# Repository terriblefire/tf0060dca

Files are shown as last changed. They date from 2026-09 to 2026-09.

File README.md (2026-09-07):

# TF0060DCA








Drop-in replacement for the Taito TC0060DCA custom dual digitally-controlled
attenuator (as used on the Operation Wolf sound board, Taito schematic
W5100215A). Two LM1972 digital attenuators driven from the original 8-bit
parallel volume bus by a CH32V203C8T6 RISC-V MCU, with a measured calibration
mapping.

The primary aim of this project was to give me repro modules for my Operation 
Wolf machine but I also passed the measured curves on to MAME where they have 
been integrated. 

## Community

Questions, build reports and general chat: [join the Discord](https://discord.gg/awMzHfB86T).

## The repro matches the original

The key result of this project: measured on the [test fixture](testfixture/),
the TF0060DCA repro reproduces the original TC0060DCA's volume response to
within about 2% across the working range. Both sweeps below were taken at the
same drive level and are referenced to their full-volume (SD 255) output; the
x-axis is the machine's SD bus convention (0 = silence, 255 = full volume).
Where the curves part company at the bottom is just the two measurement runs'
differing noise floors.

Original vs repro measured response

Source data: [raw_curve_second_measure.csv](measured/raw_curve_second_measure.csv)
(original), [ch32_measured.csv](measured/ch32_measured.csv) (repro).

**Firmware response.** The repro's curve is fully explained by its firmware:
the computed line is derived from the `lm1972_mapping` table in
[main.c](firmware/CH32V203C8T6/User/main.c) and the LM1972 datasheet
attenuation values (SNAS094D Table 1): SD codes 0-86 map to LM1972 mute
(codes >= 0x7F = 100 dB), SD 87 gives -74.5 dB, SD 88 -44.5 dB, rising to
-4.5 dB at SD 255. The measured CH32 sweep matches it within about 2%
everywhere above the rig's ~ -23 dB noise floor, which hides the mute region.

CH32 firmware response, computed vs measured

## Test fixture

The fixture that produced the measurements: a Raspberry Pi Zero drives the SD
volume bus and clocks while the DUT's audio output is measured. It carries two
20-pin SIP sockets so an original TC0060DCA and the TF0060DCA replacement can
be exercised side by side.

| | |
|---|---|
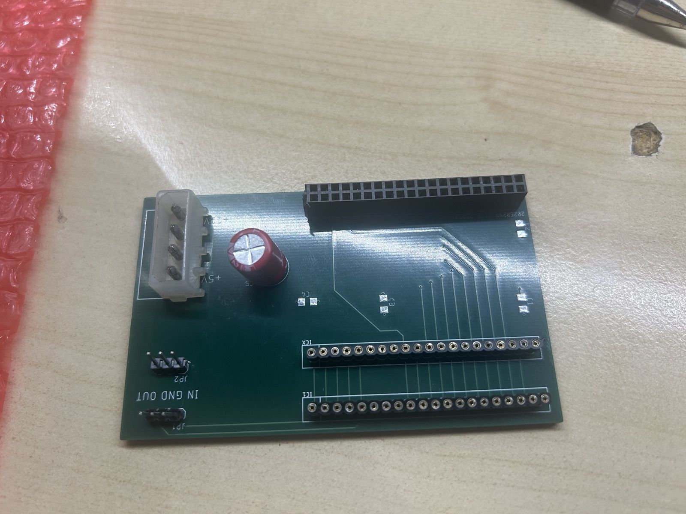
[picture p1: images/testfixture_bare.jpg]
Bare test fixture PCB
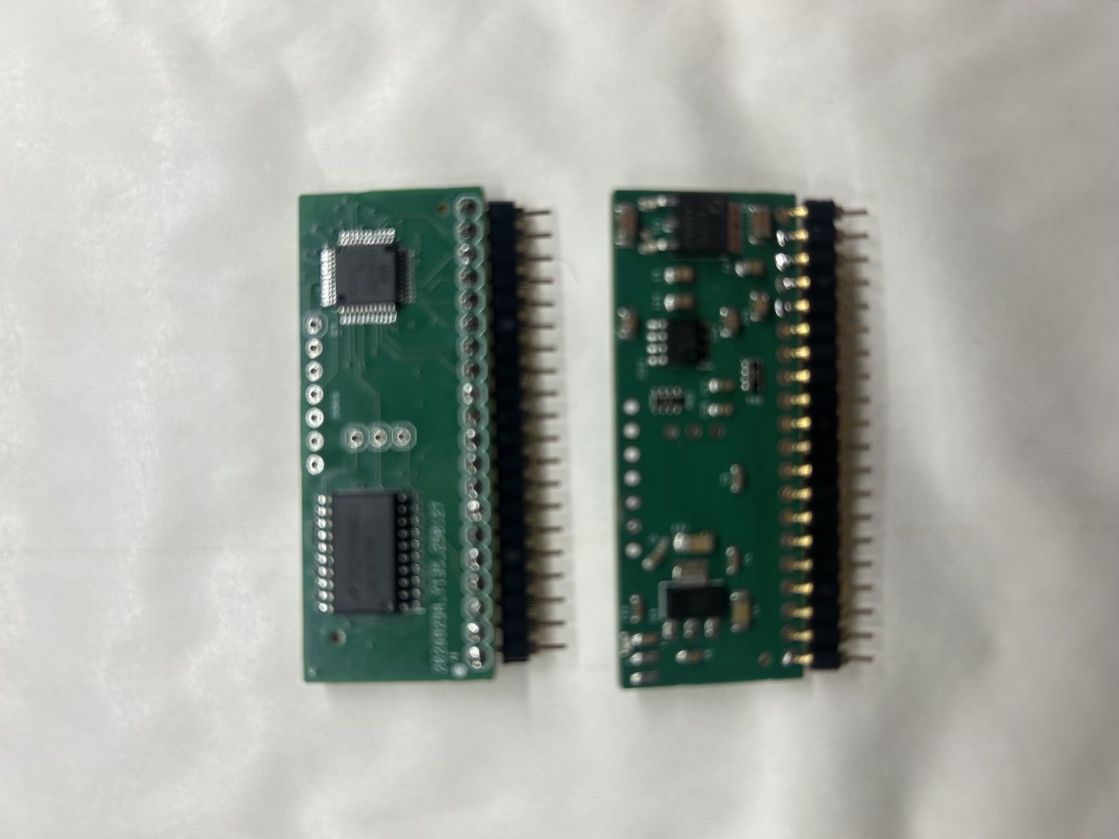
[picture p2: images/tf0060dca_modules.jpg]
Replacement modules, front and back
|  |  |
| *Bare fixture: Molex power in, Pi Zero header, two SIP-20 sockets* | *TF0060DCA replacement modules* |
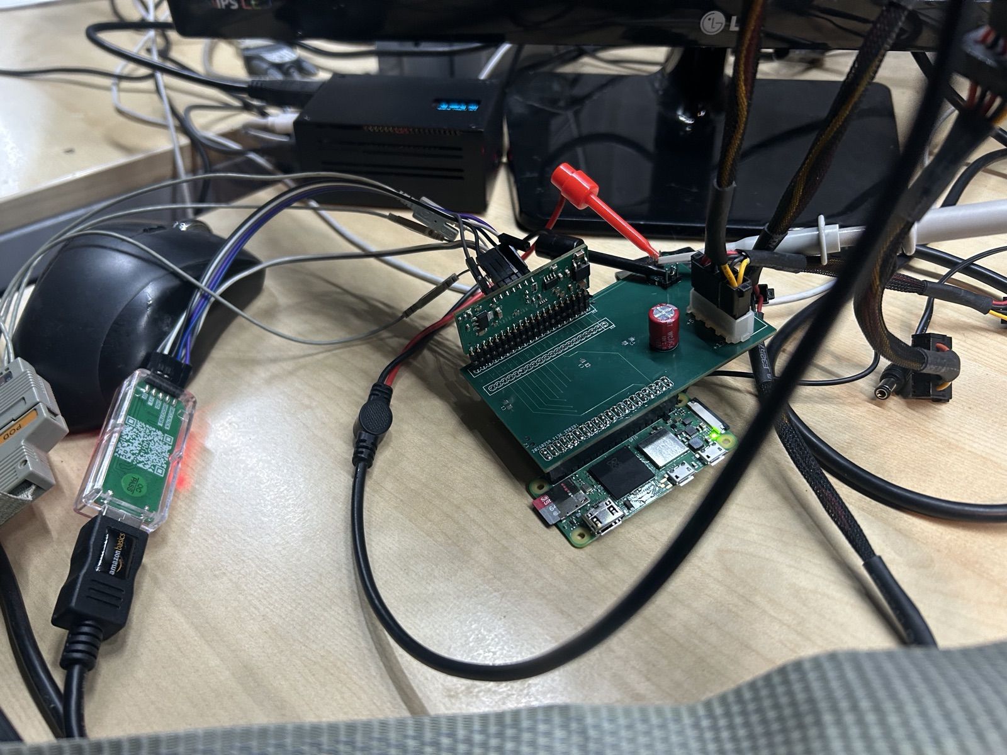
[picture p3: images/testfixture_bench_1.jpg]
Fixture on the bench
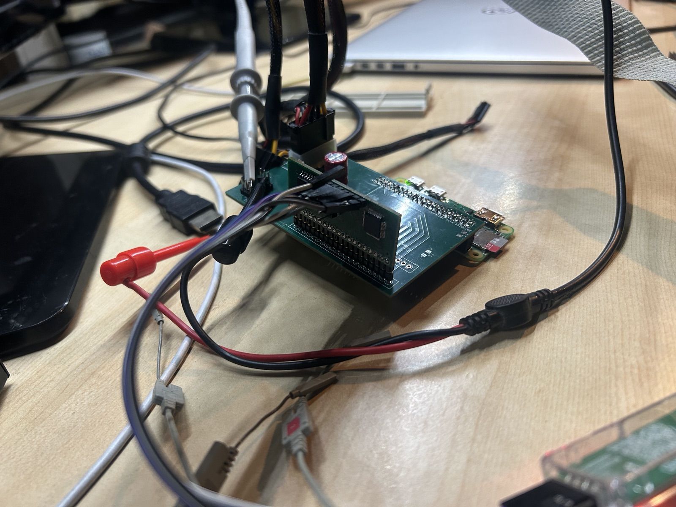
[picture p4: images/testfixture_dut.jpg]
Fixture with DUT fitted
|  |  |
| *On the bench, mounted on a Pi Zero* | *With a device under test fitted* |
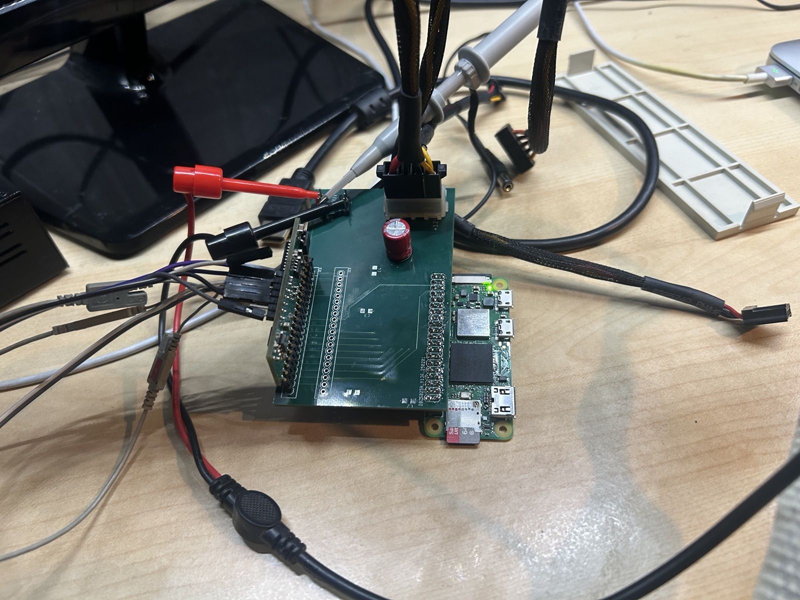
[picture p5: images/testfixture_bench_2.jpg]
Bench, second angle
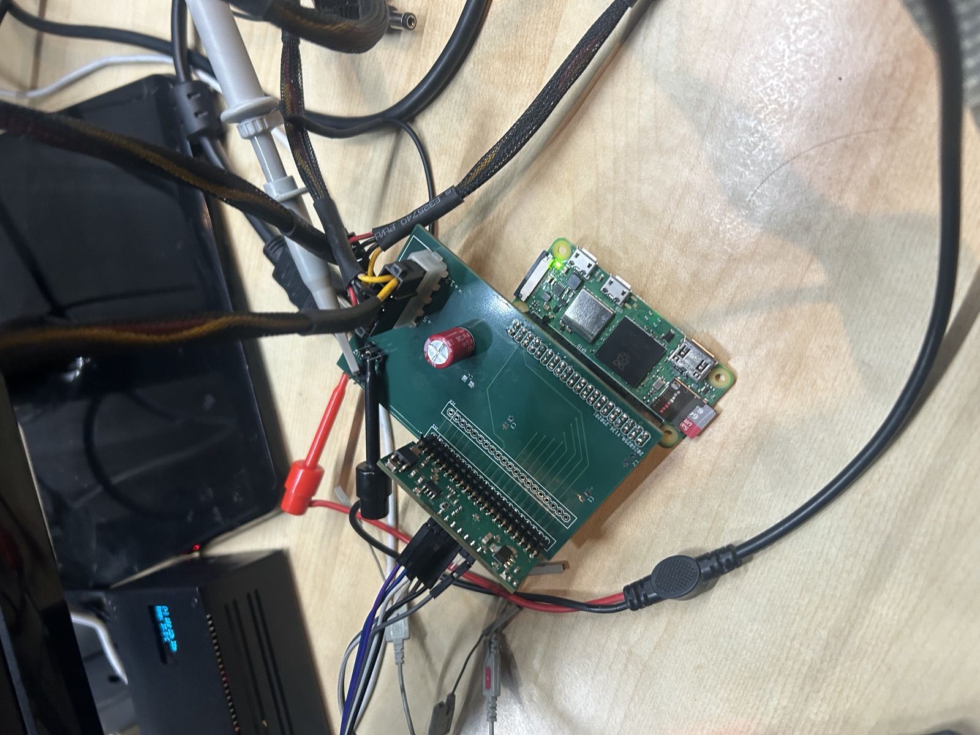
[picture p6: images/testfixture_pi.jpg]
Overhead view on the Pi Zero
|  |  |
| *Probing during a measurement run* | *Overhead: Pi Zero and fixture* |

## TC0060DCA pin 7 (V_B)

Pin 7 of the original TC0060DCA has been asked about; the evidence from the
original hardware and this project:

- **Original Taito schematic** (W5100215A, sheet 4-2, IC49): pin 7 is strapped
  directly to the same ground rail as pins 6, 10 and 20. There is no external
  bias network (no capacitor or divider). Pin 8 is drawn as an unconnected
  stub (N.C.).
- **Test fixture**: a real TC0060DCA runs correctly with pin 7 tied to GND —
  the measured response above was captured that way.
- **This replacement** leaves pin 7 unconnected (net `V_B`) and pin 8 N.C.,
  and functions in the host board.

So pin 7 is a ground-referenced bias/substrate connection ("V_B"), tied to 0 V
in the machine and carrying no signal; a replacement can safely leave it
unconnected. It is not a volume or audio pin.

## Design notes (FAQ)

**Are C8-C11, C14 and C15 polarized?** No. They are drawn with Eagle's `C-US`
device, whose American-style symbol has one straight and one curved plate for
*any* capacitor - a polarized cap in Eagle carries an explicit "+" mark, which
these don't have. Physically they are 0805 ceramic (MLCC) parts, inherently
non-polar, used as AC coupling in the audio path.

**Volume conventions.** The machine's SD bus counts up (0 = silence, 255 =
full volume). The LM1972 register counts the other way (datasheet SNAS094D
Table 1: code 0x00 = 0.0 dB, 0.5 dB/step to 47.5 dB at code 95, 1.0 dB/step
to 78 dB at code 126, codes 0x7F-0xFF = 100 dB mute). The firmware's
`lm1972_mapping` table translates between the two. The legacy
[measured/measured.csv](measured/measured.csv) is indexed by attenuation
step (0 = full volume), not by SD code.

**What value are the coupling caps?** These are AC couplers, so the exact
value is not critical - it only sets the high-pass corner, which sits far
below audio for anything in this region. The design value was a nominal 6 uF;
on the JLCPCB production run the part matcher resolved this to a 10 uF X5R
(Samsung CL21A106KOQNNNE, LCSC C1713), which is what is fitted on assembled
boards and what the schematic now records. If hand-building, 4.7 uF, 6.8 uF
or 10 uF are all fine.

- `eagle/` - EAGLE schematic/board plus CAM, BOM/CPL and check tooling
  (`make help` for targets; gerbers and PDF build via the terriblefire78
  Docker images)
- `firmware/` - CH32V203 firmware (builds in `terriblefire78/mrs:latest`,
  or `make firmware` from the repo root)
- `testfixture/` - EAGLE test fixture board
- `measured/` - measured attenuation data and calibration table generator
- `gerbers/` - manufactured revisions (JLCPCB)

## License

Copyright (c) 2026 Stephen Leary (TerribleFire).

This design and its firmware are licensed under
[Creative Commons Attribution 4.0 International](LICENSE) (CC BY 4.0): you may
use, modify, manufacture and sell derivatives for any purpose, provided you
credit the original design and work.

WCH vendor sources under `firmware/` (Nanjing Qinheng Microelectronics) retain
their own copyright notices.

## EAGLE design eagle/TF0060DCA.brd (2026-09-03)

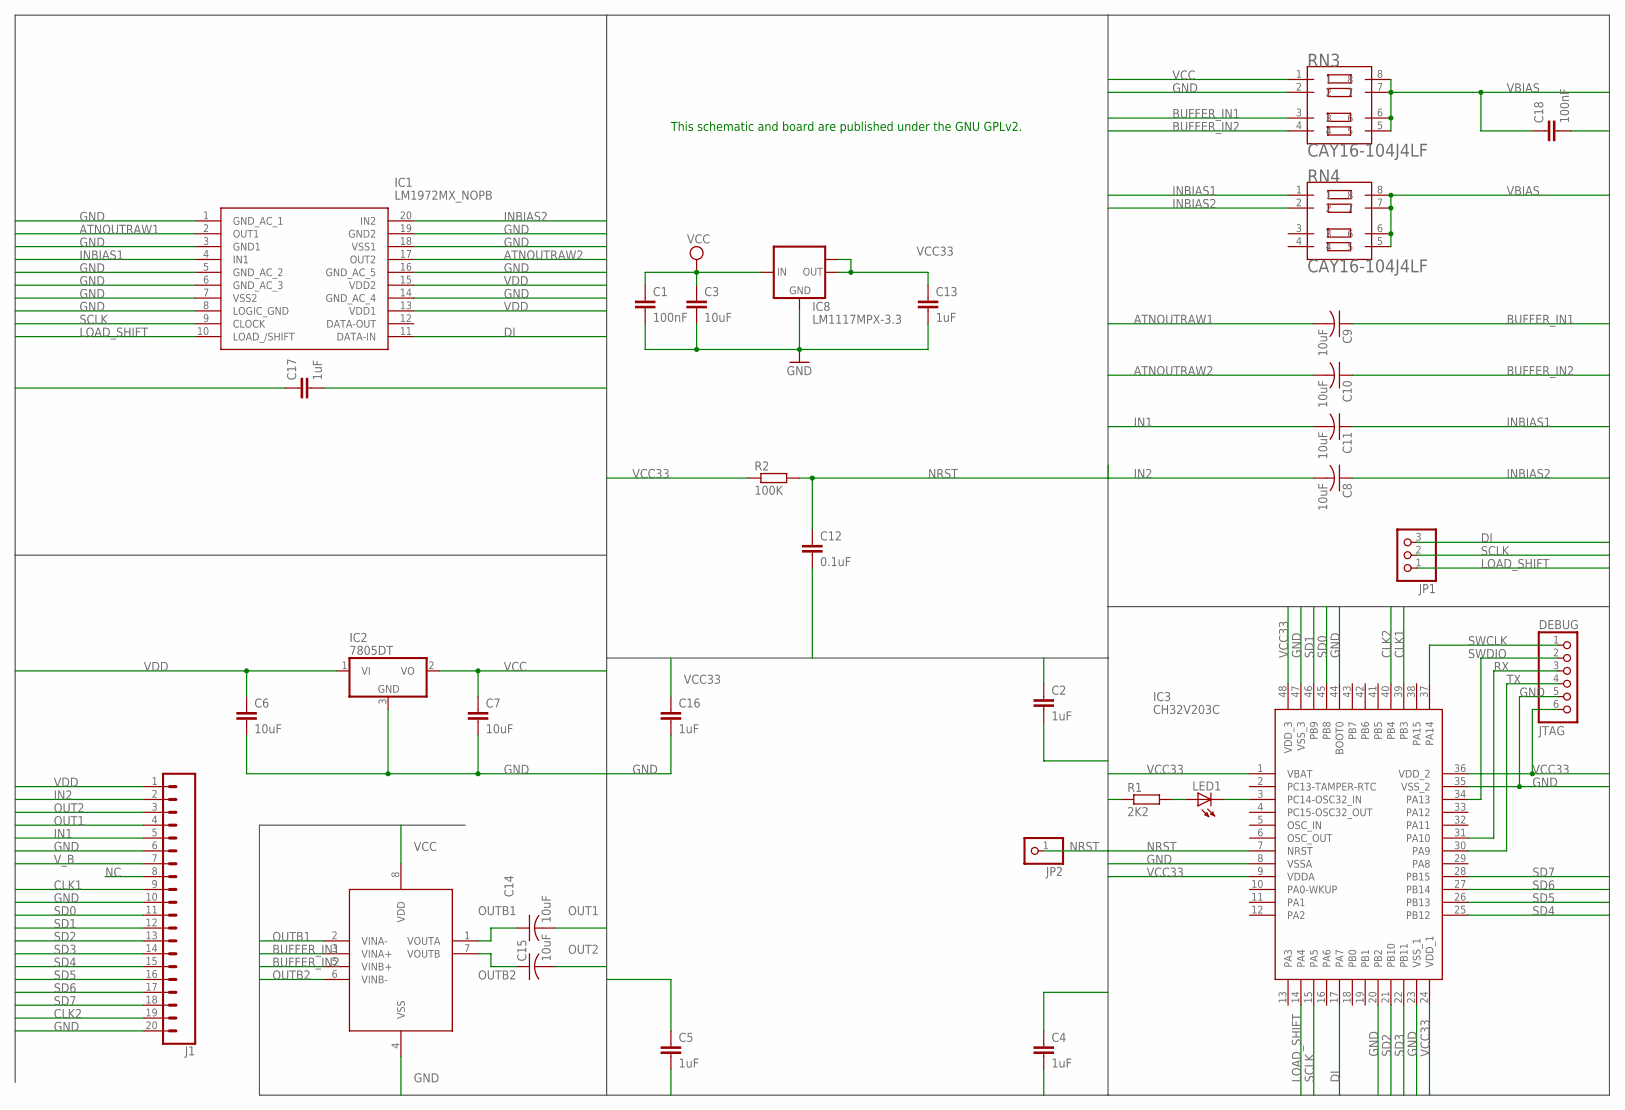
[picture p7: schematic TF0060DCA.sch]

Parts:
C1: 100nF; C1206
C2, C4, C5, C16, C17: 1uF; C0603
C3: 10uF; C0603
C6, C7: 10uF; C1206
C8, C9, C10, C11, C14, C15: 10uF; C0805
C12: 0.1uF; C0603
C13: 1uF; C1206
C18: 100nF; C0603
DEBUG: JTAG; 1X06_ROUND
IC1: LM1972MX_NOPB; SOIC127P1030X265-20N
IC2: 7805DT; TO252
IC3: CH32V203C; QFP50P900X900X160-48N
IC8: LM1117MPX-3.3; SOT223
IC12: MCP6002T-I_SN; SOIC127P600X175-8N
J1: CONN_20; 1X20
JP1: PINHD-1X3; 1X03
JP2: PINHD-1X1; 1X01
LED1: LEDCHIPLED_0603; CHIPLED_0603
R1: 2K2; R0603
R2: 100K; R0603
RN3, RN4: CAY16-104J4LF; RESCAXE80P320X160-8N

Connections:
ATNOUTRAW1: C9.2, IC1.2 (OUT1)
ATNOUTRAW2: C10.2, IC1.17 (OUT2)
BUFFER_IN1: C9.1, IC12.3 (VINA+), RN3.3
BUFFER_IN2: C10.1, IC12.5 (VINB+), RN3.4
CLK1: IC3.39 (PB3), J1.9
CLK2: IC3.40 (PB4), J1.19
DI: IC1.11 (DATA-IN), IC3.17 (PA7), JP1.3
GND: C1.2, C2.2, C3.2, C4.2, C5.2, C6.2, C7.2, C12.2, C13.2, C16.2, C17.2, C18.2, DEBUG.5, IC1.1 (GND_AC_1), IC1.3 (GND1), IC1.5 (GND_AC_2), IC1.6 (GND_AC_3), IC1.7 (VSS2), IC1.8 (LOGIC_GND), IC1.14 (GND_AC_4), IC1.16 (GND_AC_5), IC1.18 (VSS1), IC1.19 (GND2), IC2.3 (GND), IC3.8 (VSSA), IC3.20 (PB2), IC3.23 (VSS_1), IC3.35 (VSS_2), IC3.44 (BOOT0), IC3.47 (VSS_3), IC8.1 (GND), IC12.4 (VSS), J1.6, J1.10, J1.20, RN3.2
IN1: C11.2, J1.5
IN2: C8.2, J1.2
INBIAS1: C11.1, IC1.4 (IN1), RN4.1
INBIAS2: C8.1, IC1.20 (IN2), RN4.2
LOAD_SHIFT: IC1.10 (LOAD_/SHIFT), IC3.14 (PA4), JP1.1
unnamed: IC3.3 (PC14-OSC32_IN), LED1.C
unnamed: LED1.A, R1.2
NC: J1.8
NRST: C12.1, IC3.7 (NRST), JP2.1, R2.2
OUT1: C14.2, J1.4
OUT2: C15.2, J1.3
OUTB1: C14.1, IC12.1 (VOUTA), IC12.2 (VINA-)
OUTB2: C15.1, IC12.6 (VINB-), IC12.7 (VOUTB)
RX: DEBUG.3, IC3.31 (PA10)
SCLK: IC1.9 (CLOCK), IC3.15 (PA5), JP1.2
SD0: IC3.45 (PB8), J1.11
SD1: IC3.46 (PB9), J1.12
SD2: IC3.21 (PB10), J1.13
SD3: IC3.22 (PB11), J1.14
SD4: IC3.25 (PB12), J1.15
SD5: IC3.26 (PB13), J1.16
SD6: IC3.27 (PB14), J1.17
SD7: IC3.28 (PB15), J1.18
SWCLK: DEBUG.1, IC3.37 (PA14)
SWDIO: DEBUG.2, IC3.34 (PA13)
TX: DEBUG.4, IC3.30 (PA9)
VBIAS: C18.1, RN3.5, RN3.6, RN3.7, RN3.8, RN4.5, RN4.6, RN4.7, RN4.8
VCC: C1.1, C3.1, C7.1, C17.1, IC2.2 (VO), IC8.3 (IN), IC12.8 (VDD), RN3.1
VCC33: C2.1, C4.1, C5.1, C13.1, C16.1, DEBUG.6, IC3.1 (VBAT), IC3.9 (VDDA), IC3.24 (VDD_1), IC3.36 (VDD_2), IC3.48 (VDD_3), IC8.2 (OUT), IC8.TAB (OUT1), R1.1, R2.1
VDD: C6.1, IC1.13 (VDD1), IC1.15 (VDD2), IC2.1 (VI), J1.1
V_B: J1.7

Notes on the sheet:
This schematic and board are published under the GNU GPLv2.

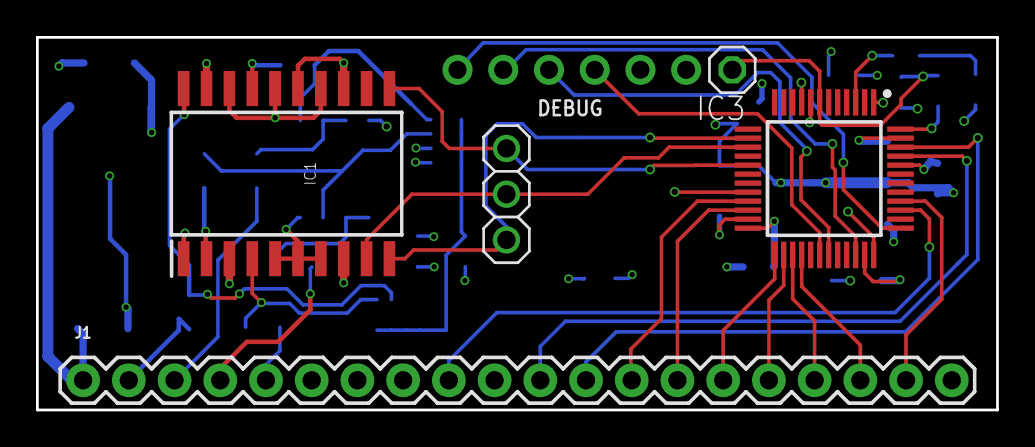
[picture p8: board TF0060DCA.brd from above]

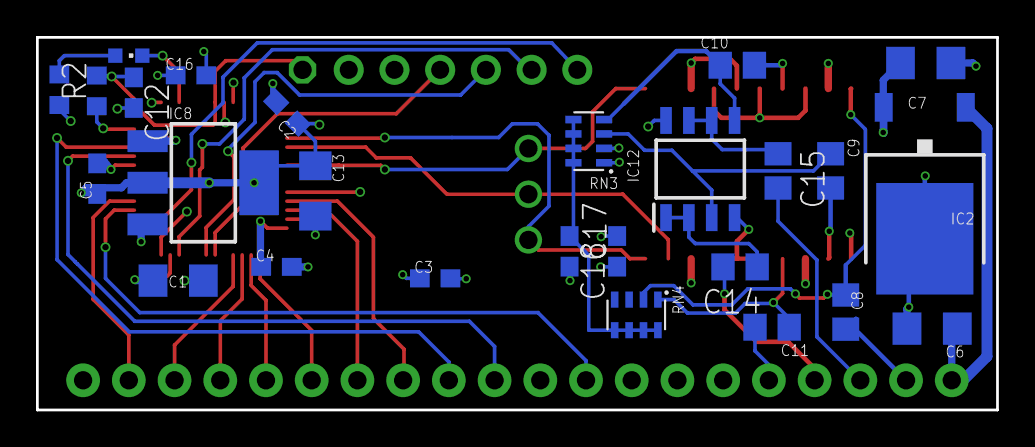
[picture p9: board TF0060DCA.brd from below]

Board: 4 copper layers, 53.3 x 20.7 mm, 32 parts (26 on the bottom side), 37 nets.

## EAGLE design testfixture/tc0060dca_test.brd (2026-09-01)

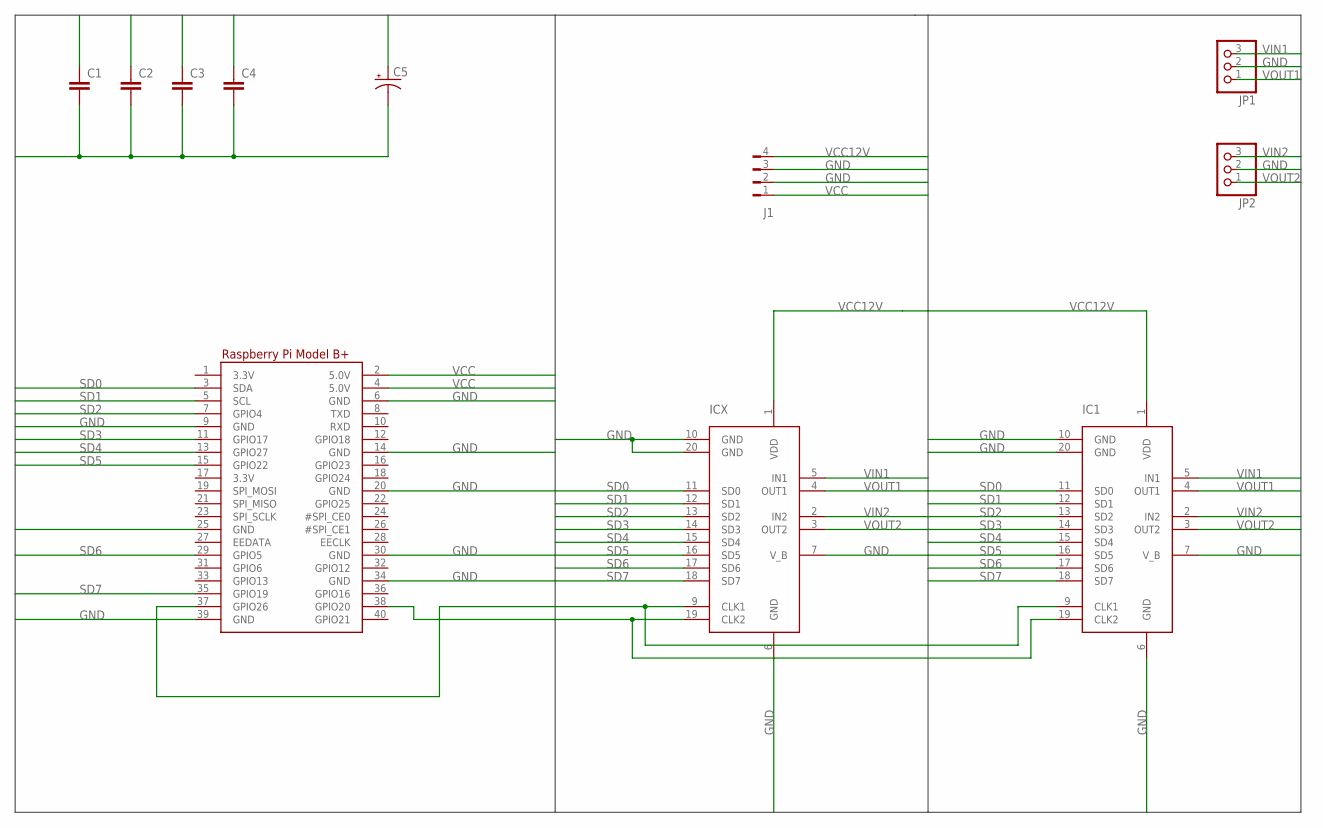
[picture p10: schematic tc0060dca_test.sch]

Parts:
C1, C2, C3, C4: CC1206; C1206
C5: CPOL-USTT5D9; TT5D9
IC1: TC0060DCA; 1X20
ICX: TC0060DCA; 1X20
J1: FLOP-4W; FLOP-4V
JP1, JP2: PINHD-1X3; 1X03
RPI1: RASPBERRYPI_BPLUS_IDC; 2X20

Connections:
GND: C1.2, C2.2, C3.2, C4.2, C5.-, IC1.6 (GND), IC1.7 (V_B), IC1.10 (GND), IC1.20 (GND), ICX.6 (GND), ICX.7 (V_B), ICX.10 (GND), ICX.20 (GND), J1.2, J1.3, JP1.2, JP2.2, RPI1.6 (GND), RPI1.9 (GND), RPI1.14 (GND), RPI1.20 (GND), RPI1.25 (GND), RPI1.30 (GND), RPI1.34 (GND), RPI1.39 (GND)
unnamed: IC1.9 (CLK1), ICX.9 (CLK1), RPI1.37 (GPIO26)
unnamed: IC1.19 (CLK2), ICX.19 (CLK2), RPI1.38 (GPIO20)
SD0: IC1.11 (SD0), ICX.11 (SD0), RPI1.3 (SDA)
SD1: IC1.12 (SD1), ICX.12 (SD1), RPI1.5 (SCL)
SD2: IC1.13 (SD2), ICX.13 (SD2), RPI1.7 (GPIO4)
SD3: IC1.14 (SD3), ICX.14 (SD3), RPI1.11 (GPIO17)
SD4: IC1.15 (SD4), ICX.15 (SD4), RPI1.13 (GPIO27)
SD5: IC1.16 (SD5), ICX.16 (SD5), RPI1.15 (GPIO22)
SD6: IC1.17 (SD6), ICX.17 (SD6), RPI1.29 (GPIO5)
SD7: IC1.18 (SD7), ICX.18 (SD7), RPI1.35 (GPIO19)
VCC: C1.1, C2.1, C3.1, J1.1, RPI1.2 (5.0V), RPI1.4 (5.0V)
VCC12V: C4.1, C5.+, IC1.1 (VDD), ICX.1 (VDD), J1.4
VIN1: IC1.5 (IN1), ICX.5 (IN1), JP1.3
VIN2: IC1.2 (IN2), ICX.2 (IN2), JP2.3
VOUT1: IC1.4 (OUT1), ICX.4 (OUT1), JP1.1
VOUT2: IC1.3 (OUT2), ICX.3 (OUT2), JP2.1

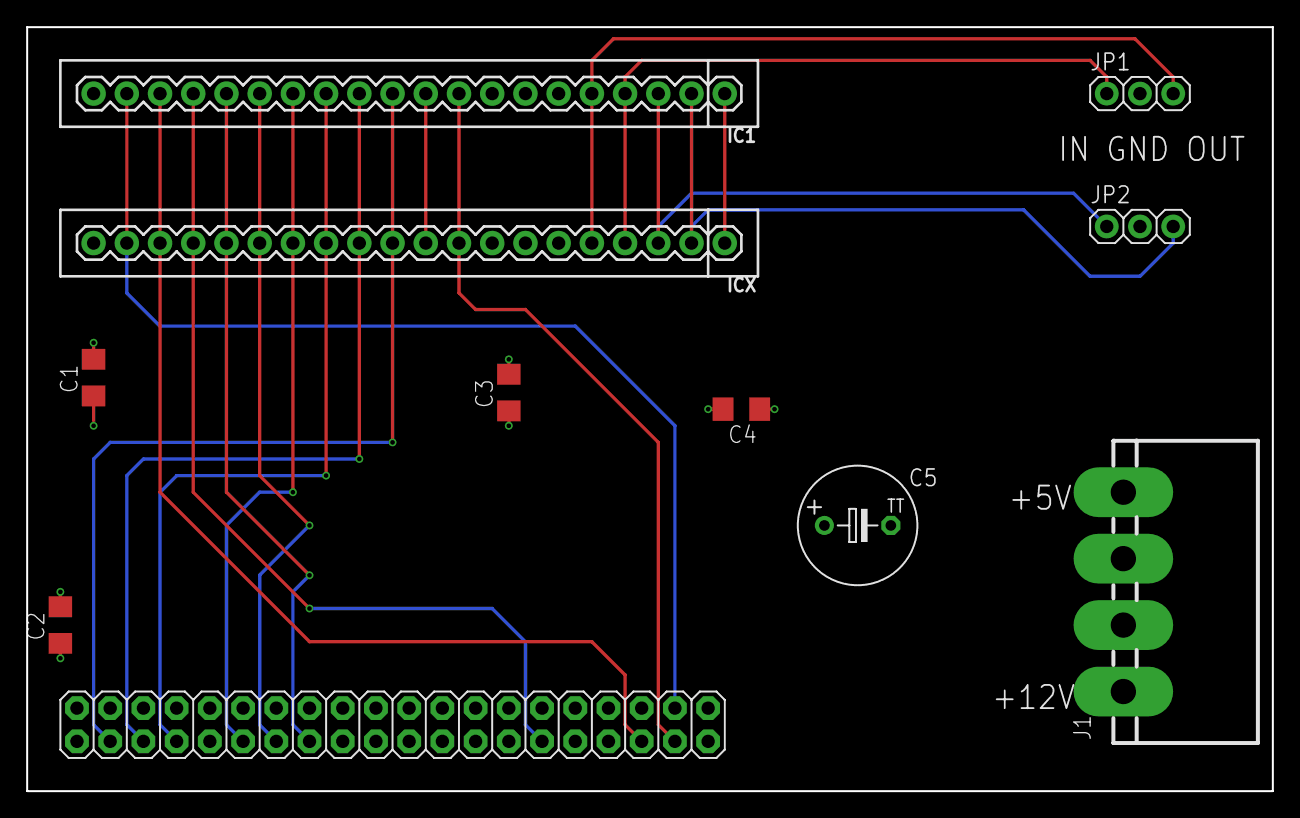
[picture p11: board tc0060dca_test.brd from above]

Board: 4 copper layers, 95.2 x 58.4 mm, 11 parts (0 on the bottom side), 17 nets.

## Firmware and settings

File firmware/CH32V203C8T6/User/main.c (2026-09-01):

/********************************** (C) COPYRIGHT *******************************
 * File Name          : main.c
 * Author             : WCH
 * Version            : V1.0.0
 * Date               : 2021/06/06
 * Description        : Main program body.
 *********************************************************************************
 * Copyright (c) 2021 Nanjing Qinheng Microelectronics Co., Ltd.
 * Attention: This software (modified or not) and binary are used for 
 * microcontroller manufactured by Nanjing Qinheng Microelectronics.
 *******************************************************************************/

/*
 *@Note
 *USART Print debugging routine:
 *USART1_Tx(PA9).
 *This example demonstrates using USART1(PA9) as a print debug port output.
 *
 */

#include "debug.h"

#define LM1972_CH1_ADDRESS 0 
#define LM1972_CH2_ADDRESS 1

#define LM1972_VOL_MAX     0
#define LM1972_VOL_MUTE    128

static u_int8_t lm1972_mapping[] = {0x80,0x7F,0x7F,0x7F,0x7F,0x7F,0x7F,0x7F,0x7F,0x7F,0x7F,0x7F,0x7F,0x7F,0x7F,0x7F,
                                    0x7F,0x7F,0x7F,0x7F,0x7F,0x7F,0x7F,0x7F,0x7F,0x7F,0x7F,0x7F,0x7F,0x7F,0x7F,0x7F,
                                    0x7F,0x7F,0x7F,0x7F,0x7F,0x7F,0x7F,0x7F,0x7F,0x7F,0x7F,0x7F,0x7F,0x7F,0x7F,0x7F,
                                    0x7F,0x7F,0x7F,0x7F,0x7F,0x7F,0x7F,0x7F,0x7F,0x7F,0x7F,0x7F,0x7F,0x7F,0x7F,0x7F,
                                    0x7F,0x7F,0x7F,0x7F,0x7F,0x7F,0x7F,0x7F,0x7F,0x7F,0x7F,0x7F,0x7F,0x7F,0x7F,0x7F,
                                    0x7F,0x7F,0x7F,0x7F,0x7F,0x7F,0x7F,0x7A,0x59,0x50,0x48,0x43,0x41,0x3E,0x3C,0x3A,
                                    0x39,0x37,0x36,0x35,0x34,0x33,0x32,0x31,0x30,0x2F,0x2E,0x2D,0x2C,0x2B,0x2B,0x2A,
                                    0x29,0x28,0x28,0x27,0x26,0x26,0x25,0x24,0x24,0x23,0x23,0x22,0x22,0x21,0x21,0x20,
                                    0x20,0x1F,0x1F,0x1E,0x1E,0x1D,0x1D,0x1C,0x1C,0x1B,0x1B,0x1A,0x1A,0x19,0x19,0x18,
                                    0x18,0x17,0x17,0x17,0x16,0x16,0x16,0x15,0x15,0x14,0x14,0x14,0x14,0x13,0x13,0x13,
                                    0x12,0x12,0x12,0x12,0x11,0x11,0x11,0x11,0x10,0x10,0x10,0x10,0x10,0x0F,0x0F,0x0F,
                                    0x0F,0x0E,0x0E,0x0E,0x0E,0x0E,0x0E,0x0D,0x0D,0x0D,0x0D,0x0D,0x0D,0x0C,0x0C,0x0C,
                                    0x0C,0x0C,0x0C,0x0C,0x0B,0x0B,0x0B,0x0B,0x0B,0x0B,0x0B,0x0B,0x0B,0x0B,0x0A,0x0A,
                                    0x0A,0x0A,0x0A,0x0A,0x0A,0x0A,0x0A,0x0A,0x0A,0x0A,0x0A,0x0A,0x0A,0x0A,0x09,0x09,
                                    0x09,0x09,0x09,0x09,0x09,0x09,0x09,0x09,0x09,0x09,0x09,0x09,0x09,0x09,0x09,0x09,
                                    0x09,0x09,0x09,0x09,0x09,0x09,0x09,0x09,0x09,0x09,0x09,0x09,0x09,0x09,0x09,0x09};

static uint16_t ch1_volume_data = 255;
static uint16_t ch1_volume_last = 0;

static uint16_t ch2_volume_data = 255;
static uint16_t ch2_volume_last = 0;

void CLK1_IRQ (void) __attribute__ ((interrupt ("WCH-Interrupt-fast")));  // Line 3
void CLK2_IRQ (void) __attribute__ ((interrupt ("WCH-Interrupt-fast")));  // Line 4

void CLK1_IRQ (void) {
    EXTI->INTFR = EXTI_Line3;
    ch1_volume_data = (uint16_t)GPIOB->INDR >> 8;
    return;
}

void CLK2_IRQ (void) {
    EXTI->INTFR = EXTI_Line4;
    ch2_volume_data = (uint16_t)GPIOB->INDR >> 8;
    return;
}


/*********************************************************************
 * @fn      SPI1_ReadWriteByte
 *
 * @brief   SPI1 read or write one byte.
 *
 * @param   TxData - write one byte data.
 *
 * @return  Read one byte data.
 */
void SPI1_WriteByte(u8 TxData)
{
    u8 i = 0;
    while(SPI_I2S_GetFlagStatus(SPI1, SPI_I2S_FLAG_TXE) == RESET);
    SPI_I2S_SendData(SPI1, TxData);
    i = 0;
}

void SPI1_WriteChannel(u8 chan, u8 val)
{
    GPIO_WriteBit (GPIOA, GPIO_Pin_4, Bit_RESET); 
    SPI1_WriteByte(chan);
    SPI1_WriteByte(lm1972_mapping[val]);
    //SPI1_WriteByte(val);
    Delay_Us (10);
    GPIO_WriteBit (GPIOA, GPIO_Pin_4, Bit_SET); 
}


/*********************************************************************
 * @fn      SPI_1Lines_HalfDuplex_Init
 *
 * @brief   Configuring the SPI for half-duplex communication.
 *
 * @return  none
 */
void SPI_1Lines_HalfDuplex_Init(void)
{
    printf("Entering SPI_1Lines_HalfDuplex_Init\r\n");
	GPIO_InitTypeDef GPIO_InitStructure={0};
	SPI_InitTypeDef SPI_InitStructure={0};
	NVIC_InitTypeDef NVIC_InitStructure={0};

	RCC_APB2PeriphClockCmd( RCC_APB2Periph_GPIOA | RCC_APB2Periph_SPI1, ENABLE );

    GPIO_InitStructure.GPIO_Pin = GPIO_Pin_4;
	GPIO_InitStructure.GPIO_Mode = GPIO_Mode_Out_PP;
	GPIO_InitStructure.GPIO_Speed = GPIO_Speed_50MHz;
	GPIO_Init( GPIOA, &GPIO_InitStructure );

	GPIO_InitStructure.GPIO_Pin = GPIO_Pin_5;
	GPIO_InitStructure.GPIO_Mode = GPIO_Mode_AF_PP;
	GPIO_InitStructure.GPIO_Speed = GPIO_Speed_50MHz;
	GPIO_Init( GPIOA, &GPIO_InitStructure );

	GPIO_InitStructure.GPIO_Pin = GPIO_Pin_7;
	GPIO_InitStructure.GPIO_Mode = GPIO_Mode_AF_PP;
	GPIO_InitStructure.GPIO_Speed = GPIO_Speed_50MHz;
	GPIO_Init( GPIOA, &GPIO_InitStructure );


	SPI_InitStructure.SPI_Direction = SPI_Direction_1Line_Tx;
	SPI_InitStructure.SPI_Mode = SPI_Mode_Master;

	SPI_InitStructure.SPI_DataSize = SPI_DataSize_8b;
	SPI_InitStructure.SPI_CPOL = SPI_CPOL_Low;
	SPI_InitStructure.SPI_CPHA = SPI_CPHA_1Edge;
	SPI_InitStructure.SPI_NSS = SPI_NSS_Soft;

	SPI_InitStructure.SPI_BaudRatePrescaler = SPI_BaudRatePrescaler_64;
	SPI_InitStructure.SPI_FirstBit = SPI_FirstBit_MSB;
	SPI_InitStructure.SPI_CRCPolynomial = 7;
	SPI_Init( SPI1, &SPI_InitStructure );

	NVIC_InitStructure.NVIC_IRQChannelCmd = DISABLE;
	NVIC_Init(&NVIC_InitStructure);

	SPI_Cmd( SPI1, ENABLE );

}


/*********************************************************************
 * @fn      main
 *
 * @brief   Main program.
 *
 * @return  none
 */
int main (void) {
    NVIC_PriorityGroupConfig (NVIC_PriorityGroup_1);
    SystemCoreClockUpdate();
    Delay_Init();
    USART_Printf_Init (115200);
    printf ("SystemClk:%d\r\n", SystemCoreClock);
    printf ("ChipID:%08x\r\n", DBGMCU_GetCHIPID());
    printf ("This is printf example\r\n");

    SPI_1Lines_HalfDuplex_Init();


    EXTI_InitTypeDef EXTI_InitStructure = {0};

    RCC_APB2PeriphClockCmd (RCC_APB2Periph_AFIO, ENABLE);

    RCC_APB2PeriphClockCmd (RCC_APB2Periph_GPIOA, ENABLE);
    RCC_APB2PeriphClockCmd (RCC_APB2Periph_GPIOB, ENABLE);
    RCC_APB2PeriphClockCmd (RCC_APB2Periph_GPIOC, ENABLE);
    RCC_APB2PeriphClockCmd (RCC_APB2Periph_AFIO, ENABLE);

    // Data in - technically shoudn't be required as those values should be defauls values
    GPIO_InitTypeDef GPIO_InitStructure = {0};
    GPIO_InitStructure.GPIO_Pin = GPIO_Pin_8 | GPIO_Pin_9 | GPIO_Pin_10 | GPIO_Pin_11 | GPIO_Pin_12 | GPIO_Pin_13 | GPIO_Pin_14 | GPIO_Pin_15;
    GPIO_InitStructure.GPIO_Mode = GPIO_Mode_IPD;
    GPIO_Init (GPIOB, &GPIO_InitStructure);

    // LED PC14

    GPIO_InitStructure.GPIO_Pin = GPIO_Pin_14;
    GPIO_InitStructure.GPIO_Mode = GPIO_Mode_Out_PP;
    GPIO_InitStructure.GPIO_Speed = GPIO_Speed_50MHz;
    GPIO_Init (GPIOC, &GPIO_InitStructure);


    GPIO_EXTILineConfig (GPIO_PortSourceGPIOB, GPIO_PinSource3);
    EXTI_InitStructure.EXTI_Line = EXTI_Line3;
    EXTI_InitStructure.EXTI_Mode = EXTI_Mode_Interrupt;
    EXTI_InitStructure.EXTI_Trigger = EXTI_Trigger_Falling;
    EXTI_InitStructure.EXTI_LineCmd = ENABLE;
    EXTI_Init (&EXTI_InitStructure);

    GPIO_EXTILineConfig (GPIO_PortSourceGPIOB, GPIO_PinSource4);
    EXTI_InitStructure.EXTI_Line = EXTI_Line4;
    EXTI_InitStructure.EXTI_Mode = EXTI_Mode_Interrupt;
    EXTI_InitStructure.EXTI_Trigger = EXTI_Trigger_Falling;
    EXTI_InitStructure.EXTI_LineCmd = ENABLE;
    EXTI_Init (&EXTI_InitStructure);

    NVIC_EnableIRQ (EXTI3_IRQn);
    NVIC_SetPriority (EXTI3_IRQn, 0);
    SetVTFIRQ ((u32)CLK1_IRQ, EXTI3_IRQn, 0, ENABLE);

    NVIC_EnableIRQ (EXTI4_IRQn);
    NVIC_SetPriority (EXTI4_IRQn, 0);
    SetVTFIRQ ((u32)CLK2_IRQ, EXTI4_IRQn, 1, ENABLE);


    while (1) {

        if (ch1_volume_data != ch1_volume_last)
        {
            ch1_volume_last = ch1_volume_data;
            printf("CH1: %02x = %02x\r\n", ch1_volume_last, lm1972_mapping[ch1_volume_last]);
            GPIO_WriteBit (GPIOC, GPIO_Pin_14, Bit_RESET);  // Led ON/OFF
            Delay_Ms (1);
        }

        if (ch2_volume_data != ch2_volume_last)
        {
            ch2_volume_last = ch2_volume_data;
            
            printf("CH1: %02x = %02x\r\n", ch2_volume_last, lm1972_mapping[ch2_volume_last]);
            GPIO_WriteBit (GPIOC, GPIO_Pin_14, Bit_RESET);  // Led ON/OFF
            Delay_Ms (1);
        }

        SPI1_WriteChannel(LM1972_CH1_ADDRESS, ch1_volume_last);
        SPI1_WriteChannel(LM1972_CH2_ADDRESS, ch2_volume_last);

        GPIO_WriteBit (GPIOC, GPIO_Pin_14, Bit_SET);
        Delay_Ms (1);
    }
}

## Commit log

2026-09-01 ⏺ Restructure repo for automated Docker-based builds
    - Move TF0060DCA.brd/.sch into eagle/ to match revega/OpWolf layout
    - Pool shared Eagle tooling from revega: Makefile, extract_bom.py,
    extract_cpl.py, check_polygons.py, jlcpcb_4_layer_v9.cam
    - Add CI workflows: gerbers, schematic PDF, assembly (BOM/CPL),
    firmware build (terriblefire78/mrs:latest) and tagged release bundle
    - Add top-level Makefile driving eagle and containerised firmware builds
    - Fix hardcoded MounRiver Windows paths in generated obj/ makefiles
    - Ignore only firmware build outputs (*.elf/*.hex/*.map/*.lst) so the
    generated makefiles under obj/ are tracked for CI
    - Remove redundant rtl/ CPLD flow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
    [TF0060DCA.brd, TF0060DCA.sch, TF0060DCA_bom.csv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]
2026-09-01 Document TC0060DCA pin 7 (V_B) findings and add measured vs ideal response chart
    [TF0060DCA_bom.csv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]
2026-09-01 Grant gerbers workflow release upload permission
2026-09-03 Correct C8-C11,C14,C15 value to 10uF as fitted in production (LCSC C1713)
    [TF0060DCA.brd, TF0060DCA.sch]
2026-09-03 Add design notes FAQ: coupling cap polarity and value
2026-09-07 Rebuild response graphs on SD-code axis from firmware table and bench sweeps
    [raw_curve_second_measure.csv, repro_measure.csv, response_half_volt_pp.csv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]
2026-09-07 Validate firmware response chart against measured CH32 sweep
    [ch32_measured.csv]

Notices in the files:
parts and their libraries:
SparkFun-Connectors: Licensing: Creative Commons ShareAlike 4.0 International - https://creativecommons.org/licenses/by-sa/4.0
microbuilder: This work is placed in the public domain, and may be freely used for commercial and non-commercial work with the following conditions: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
